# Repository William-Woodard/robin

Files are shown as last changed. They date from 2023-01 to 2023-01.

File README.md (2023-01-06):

# Robin PCB
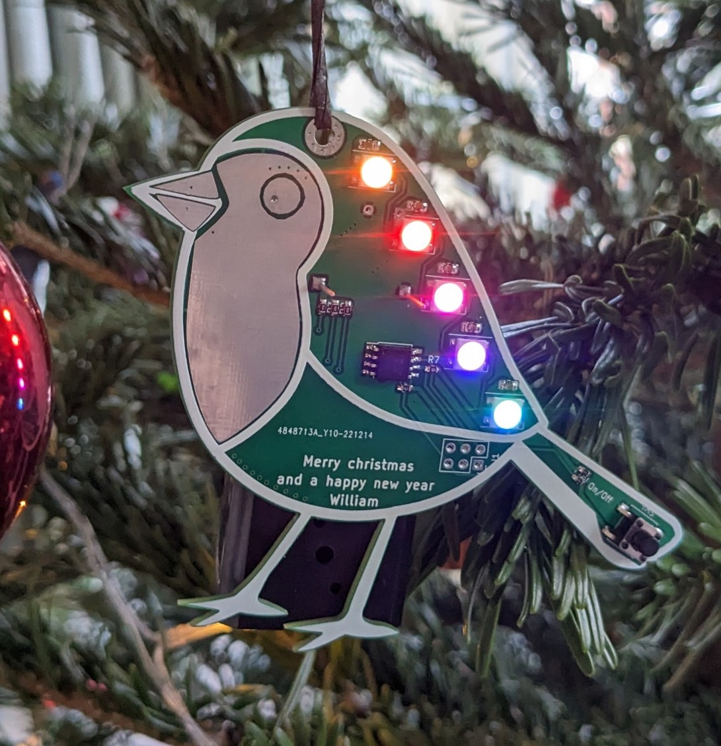
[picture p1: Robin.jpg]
Picture of the PCB

Over Christmas 2022 I made 20 Christmas themed Robin PCBs. Powered by an Attiny85, each PCB has 5 neopixels so show pretty patterns and a buzzer so it can play Christmas music. They have 2 AA batteries and an off switch meaning they should last longer than last years!

## Robin Instructions

Turn the Robin on or off with the button located on the tail. Every time you turn it on it rotates between 2 different patterns. To make it play music, press firmly on one of the spots marked below. You may have to have slightly sweaty hands for it to work :)

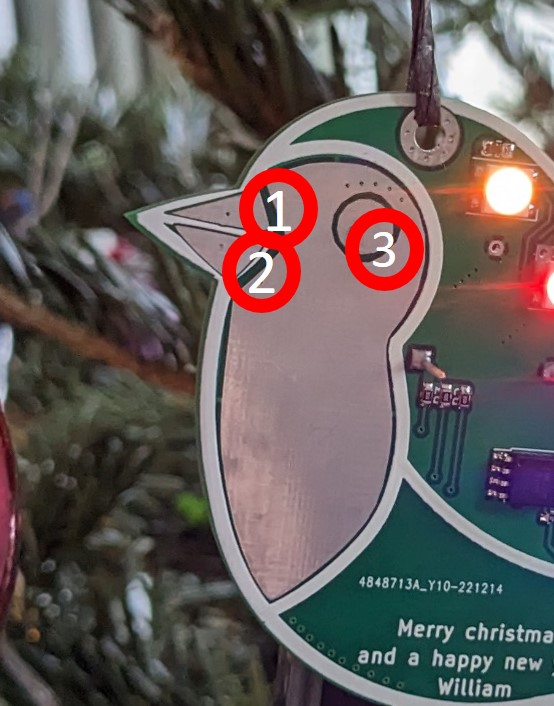
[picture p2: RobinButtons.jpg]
Buttons to press for music


Instead of having 3 buttons for the Christmas songs, I connected 3 of the gpios from the microcontroller to 3 exposed copper pads on the pcb (the eye and the 2 beaks). These are pulled high by a 200k resistor but if you press between the copper pad and ground as shown in the diagram below, you pull the voltage down as current flows through the moisture on your finger. The microcontroller detects that the voltage is reduced so plays a song.

## The assembly process

* I first used a stencil to apply solder paste to the robin
* I then used tweesers to place all the parts onto the board
* I used a hot plate to reflow solder all the components
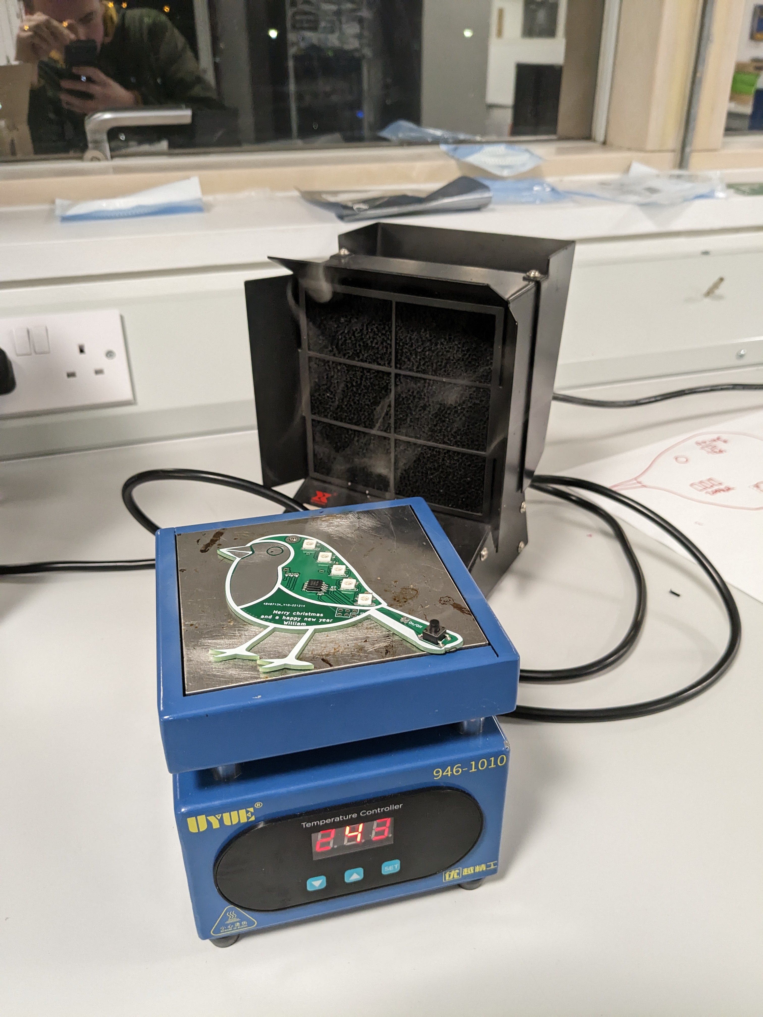
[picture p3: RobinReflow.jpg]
A robin on a hotplate

* I used a soldering iron to attach both the battery holder (through hole) and the buzzer (on the opposite side to the rest of the components)
* I used an arduino to program the microcontroller via spi

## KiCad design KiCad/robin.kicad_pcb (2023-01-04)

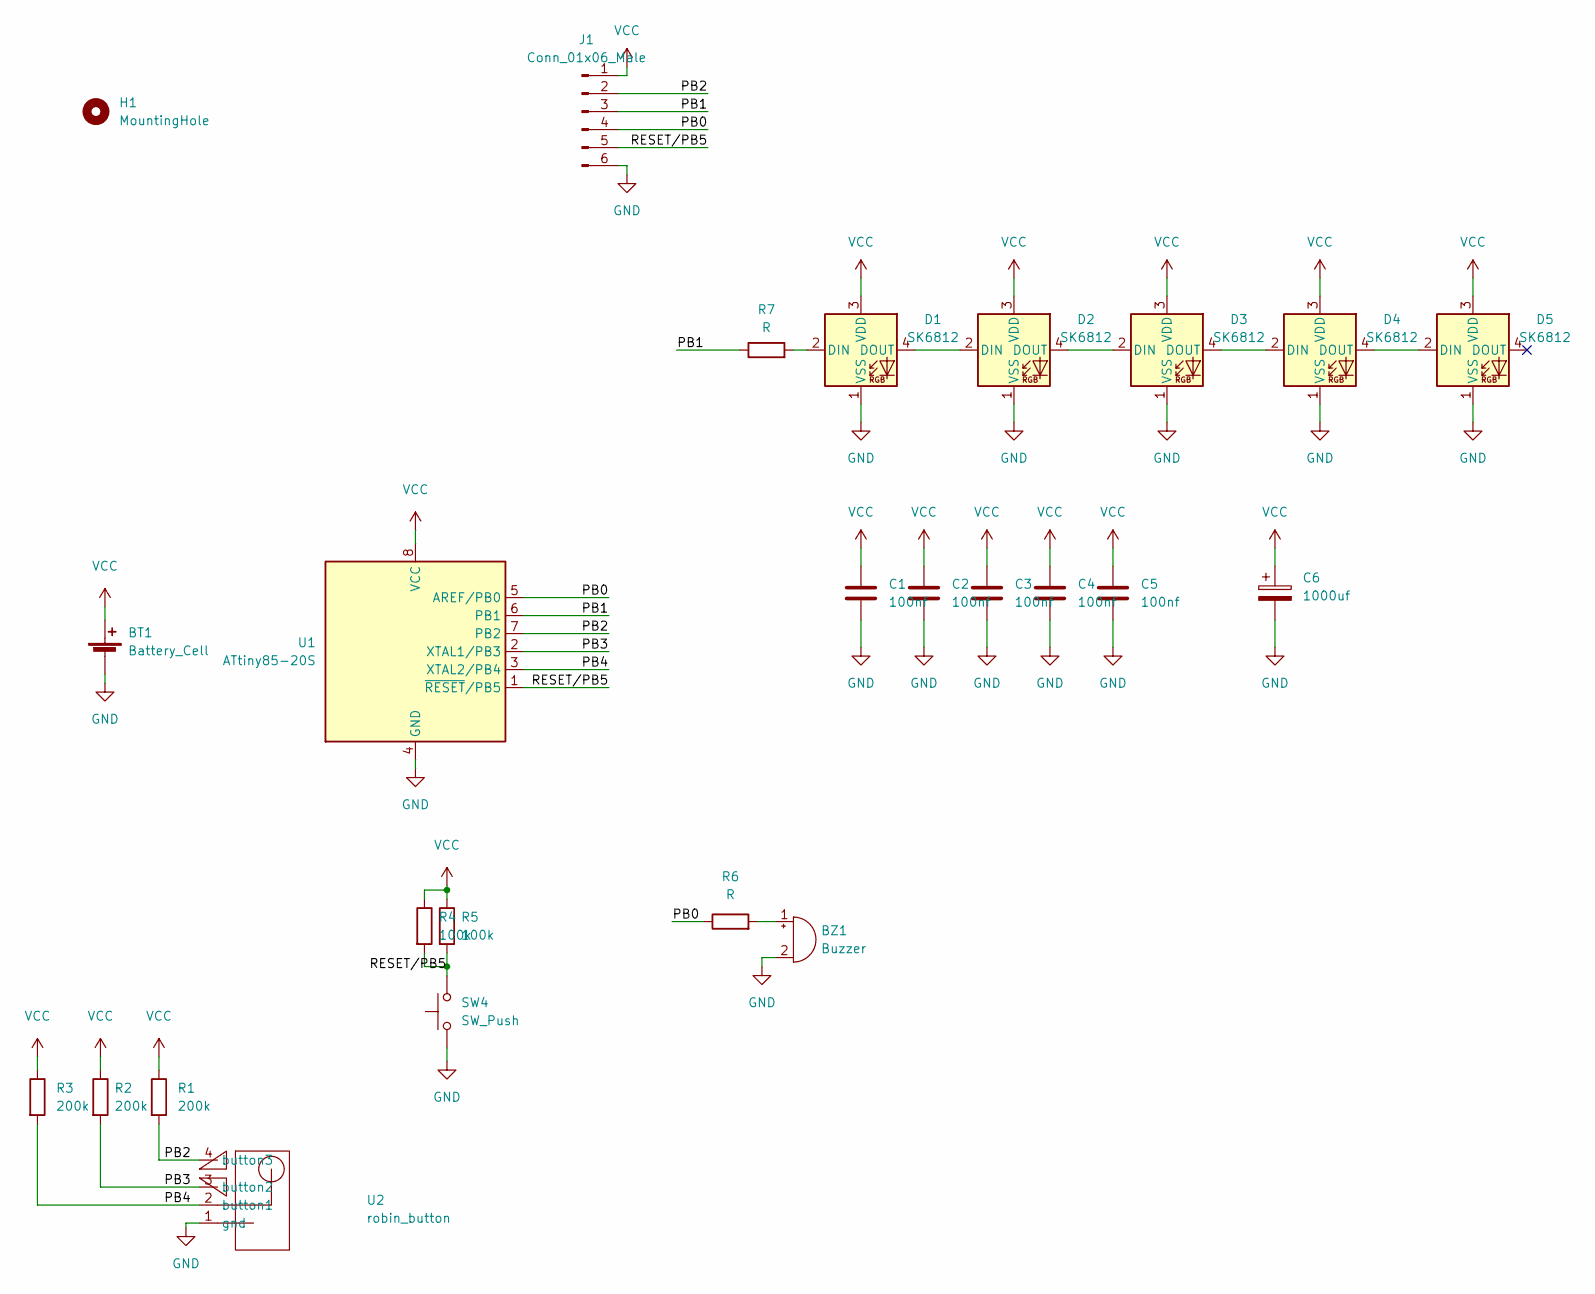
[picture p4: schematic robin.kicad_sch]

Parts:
BT1: Battery_Cell; BatteryHolder_Keystone_2462_2xAA
BZ1: Buzzer; Buzzer_CUI_CPT-9019S-SMT
C1, C2, C3, C4, C5: 100nf; C_0805_2012Metric_Pad1.18x1.45mm_HandSolder
C6: 1000uf; CP_Radial_D8.0mm_P5.00mm
D1, D2, D3, D4, D5: SK6812; LED_SK6812_PLCC4_5.0x5.0mm_P3.2mm
H1: MountingHole; MountingHole_3mm_Pad_Via
J1: Conn_01x06_Male; PinSocket_2x03_P2.54mm_Vertical
R1, R2, R3: 200k; R_0603_1608Metric
R4, R5: 100k; R_0603_1608Metric
R6, R7: R; R_0603_1608Metric
SW4: SW_Push; SW_SPST_B3S-1000
U1: ATtiny85-20S; SOIC-8W_5.3x5.3mm_P1.27mm
U2: robin_button; copp27

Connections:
/PB0: J1.4, R6.1, U1.5 (AREF/PB0)
/PB1: J1.3, R7.1, U1.6 (PB1)
/PB2: J1.2, R1.2, U1.7 (PB2), U2.4 (button3); also elsewhere on the board
/PB3: R2.2, U1.2 (XTAL1/PB3), U2.3 (button2); also elsewhere on the board
/PB4: R3.2, U1.3 (XTAL2/PB4), U2.2 (button1); also elsewhere on the board
/RESET/PB5: J1.5, R4.2, R5.2, SW4.2, U1.1 (~RESET/PB5)
GND: BT1.2 (-), BZ1.2 (+), C1.2, C2.2, C3.2, C4.2, C5.2, C6.2, D1.1 (VSS), D2.1 (VSS), D3.1 (VSS), D4.1 (VSS), D5.1 (VSS), J1.6, SW4.1, U1.4 (GND), U2.1 (gnd); also elsewhere on the board
unnamed: BZ1.1 (-), R6.2
unnamed: D1.2 (DIN), R7.2
unnamed: D1.4 (DOUT), D2.2 (DIN)
unnamed: D2.4 (DOUT), D3.2 (DIN)
unnamed: D3.4 (DOUT), D4.2 (DIN)
unnamed: D4.4 (DOUT), D5.2 (DIN)
VCC: BT1.1 (+), C1.1, C2.1, C3.1, C4.1, C5.1, C6.1, D1.3 (VDD), D2.3 (VDD), D3.3 (VDD), D4.3 (VDD), D5.3 (VDD), J1.1, R1.1, R2.1, R3.1, R4.1, R5.1, U1.8 (VCC)

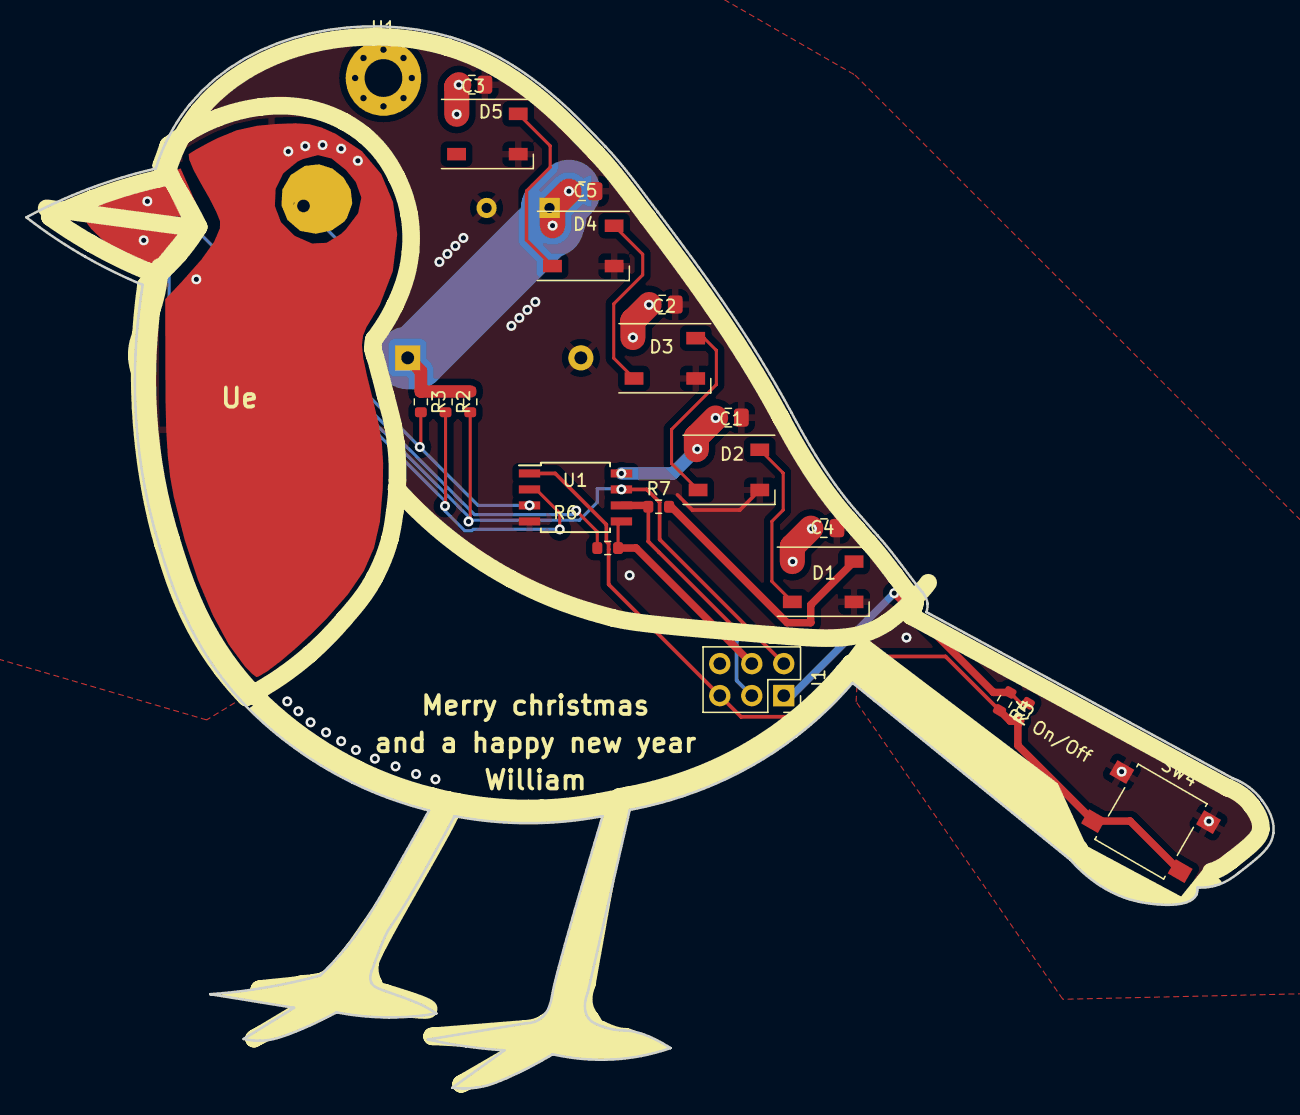
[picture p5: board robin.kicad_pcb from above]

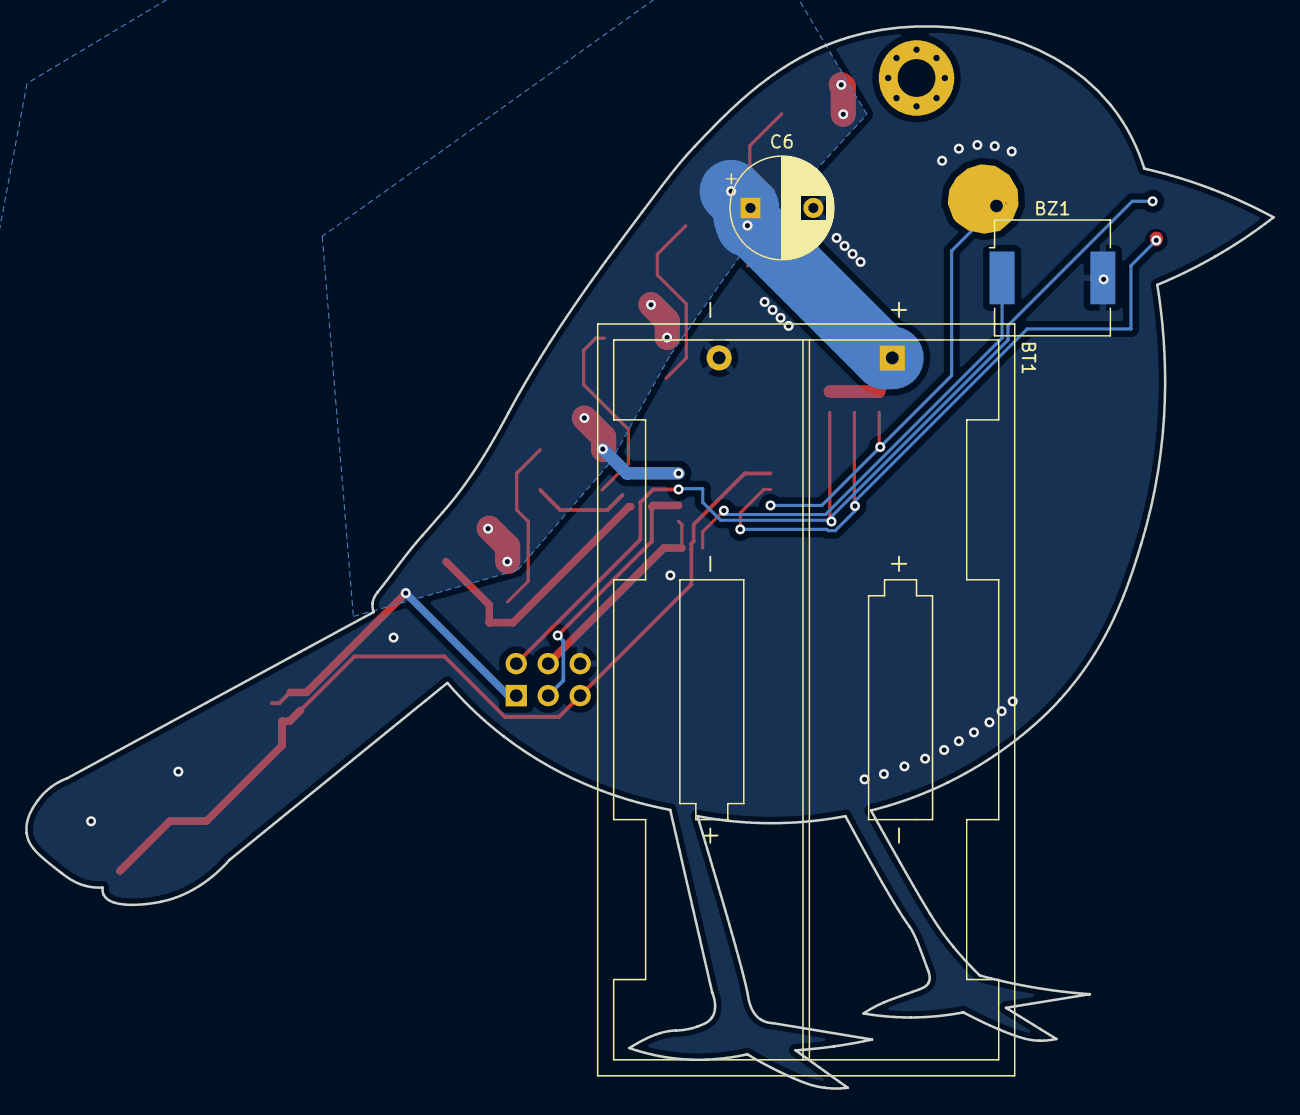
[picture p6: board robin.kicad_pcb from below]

Board: 2 copper layers, 99.1 x 84.4 mm, 25 parts (3 on the bottom side), 14 nets.

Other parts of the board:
Ue: robin_button; copp27

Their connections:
/PB2: Ue.4 (button3); also elsewhere on the board
/PB3: Ue.3 (button2); also elsewhere on the board
/PB4: Ue.2 (button1); also elsewhere on the board
GND: Ue.1 (gnd); also elsewhere on the board

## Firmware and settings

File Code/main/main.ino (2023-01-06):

//Libraries
#include <FastLED.h>
#include "pitches.h"
#include <avr/sleep.h>
#include <EEPROM.h>





//----------------------------------------Constants-----------------------------------
#define BUTTON_THRESHOLD     500   
#define GHUE_ADDITION_MUSIC 100

#define DATA_PIN    1
#define LED_TYPE    WS2811
#define COLOR_ORDER GRB
#define NUM_LEDS    5
CRGB leds[NUM_LEDS];

#define BRIGHTNESS          30
#define FRAMES_PER_SECOND  120

// Jingle Bells

int jingle_melody[] = {
  NOTE_E5, NOTE_E5, NOTE_E5,
  NOTE_E5, NOTE_E5, NOTE_E5,
  NOTE_E5, NOTE_G5, NOTE_C5, NOTE_D5,
  NOTE_E5,
  NOTE_F5, NOTE_F5, NOTE_F5, NOTE_F5,
  NOTE_F5, NOTE_E5, NOTE_E5, NOTE_E5, NOTE_E5,
  NOTE_E5, NOTE_D5, NOTE_D5, NOTE_E5,
  NOTE_D5, NOTE_G5
};

byte jingle_tempo[] = {
  8, 8, 4,
  8, 8, 4,
  8, 8, 8, 8,
  2,
  8, 8, 8, 8,
  8, 8, 8, 16, 16,
  8, 8, 8, 8,
  4, 4
};
   

// We wish you a merry Christmas
int wish_melody[] = {
  NOTE_B3, 
  NOTE_F4, NOTE_F4, NOTE_G4, NOTE_F4, NOTE_E4,
  NOTE_D4, NOTE_D4, NOTE_D4,
  NOTE_G4, NOTE_G4, NOTE_A4, NOTE_G4, NOTE_F4,
  NOTE_E4, NOTE_E4, NOTE_E4,
  NOTE_A4, NOTE_A4, NOTE_B4, NOTE_A4, NOTE_G4,
  NOTE_F4, NOTE_D4, NOTE_B3, NOTE_B3,
  NOTE_D4, NOTE_G4, NOTE_E4,
  NOTE_F4
};

byte wish_tempo[] = {
  4,
  4, 8, 8, 8, 8,
  4, 4, 4,
  4, 8, 8, 8, 8,
  4, 4, 4,
  4, 8, 8, 8, 8,
  4, 4, 8, 8,
  4, 4, 4,
  2
};

// Santa Claus is coming to town

int santa_melody[] = {
  NOTE_G4,
  NOTE_E4, NOTE_F4, NOTE_G4, NOTE_G4, NOTE_G4,
  NOTE_A4, NOTE_B4, NOTE_C5, NOTE_C5, NOTE_C5,
  NOTE_E4, NOTE_F4, NOTE_G4, NOTE_G4, NOTE_G4,
  NOTE_A4, NOTE_G4, NOTE_F4, NOTE_F4,
  NOTE_E4, NOTE_G4, NOTE_C4, NOTE_E4,
  NOTE_D4, NOTE_F4, NOTE_B3,
  NOTE_C4
};

byte santa_tempo[] = {
  8,
  8, 8, 4, 4, 4,
  8, 8, 4, 4, 4,
  8, 8, 4, 4, 4,
  8, 8, 4, 2,
  4, 4, 4, 4,
  4, 2, 4,
  1
};

//--------------------------------------------Global variables-----------------------------
byte digitalSwitch;
byte patterSwitch;

FASTLED_USING_NAMESPACE

CRGBPalette16 currentPalette;
TBlendType    currentBlending;

bool song;
long int old_millis;

bool g_robin_is_on = true;


uint8_t gHue = 0; // rotating "base color" used by many of the patterns



void setup() {
  FastLED.addLeds<LED_TYPE,DATA_PIN,COLOR_ORDER>(leds, NUM_LEDS).setCorrection(TypicalLEDStrip);
  // set master brightness control
  FastLED.setBrightness(BRIGHTNESS);

  //The on/off switch is actually the reset button. To get around this mistake there is a bit in EEPROM that is toggled
  //so it knows that if it used to be on then it should be off and vice verse
  //The other bit in EEPROM stores the previous pattern
  digitalSwitch=EEPROM.read(0);  
  patterSwitch=EEPROM.read(1);


  if (digitalSwitch==0){
    digitalSwitch=!digitalSwitch;   
    EEPROM.write(0, digitalSwitch);  
    FastLED.clear();
    FastLED.show();
    set_sleep_mode(SLEEP_MODE_PWR_DOWN);  
    sleep_enable();     
    sleep_mode(); 
    }

  else{
    digitalSwitch=!digitalSwitch;   
    EEPROM.write(0, digitalSwitch);   
    }   
  if (patterSwitch==0){
    
    patterSwitch=!patterSwitch;   
    EEPROM.write(1, patterSwitch);  
    song = 0;
    }

  else{
    patterSwitch=!patterSwitch;   
    EEPROM.write(1, patterSwitch);   
    song = 1;
    }   

   pinMode(0, OUTPUT); 
  pinMode(5,INPUT);
  
` old_millis = millis();



  currentPalette = RainbowColors_p;
  currentBlending = LINEARBLEND;

}


  
void loop()
{
  if (g_robin_is_on){
    if ((millis()-old_millis)>100){//Every 100ms checks:
    //First checks if any of the song buttons are pressed
    if (analogRead(A1)<BUTTON_THRESHOLD){
    
      int size = sizeof(jingle_melody) / sizeof(int);
        for (int thisNote = 0; thisNote < size; thisNote++) {

          // to calculate the note duration, take one second
          // divided by the note type.
          //e.g. quarter note = 1000 / 4, eighth note = 1000/8, etc.
          int noteDuration = 1000 / jingle_tempo[thisNote];
          for (int i = 0; i <= 4; i=i+2) {
            leds[i].setRGB(255,0,0);
          }
          FastLED.show();
          buzz(0, jingle_melody[thisNote], noteDuration);
        
          // to distinguish the notes, set a minimum time between them.
          // the note's duration + 30% seems to work well:
          int pauseBetweenNotes = noteDuration * 1.30;
          for (int i = 0; i <= 4; i++) {
            leds[i].setRGB(0,255,0);
          }
          FastLED.show();
          delay(pauseBetweenNotes);
        
          // stop the tone playing:
          buzz(0, 0, noteDuration);
          
        }
      }
    if (analogRead(A2)<BUTTON_THRESHOLD){
    
      int size = sizeof(santa_melody) / sizeof(int);
        for (int thisNote = 0; thisNote < size; thisNote++) {

          // to calculate the note duration, take one second
          // divided by the note type.
          //e.g. quarter note = 1000 / 4, eighth note = 1000/8, etc.
          int noteDuration = 1000 / santa_tempo[thisNote];
          for (int i = 0; i <= 4; i=i+1) {
          leds[i].setRGB(0,255,0);
          }
        
          i = santa_melody[thisNote];
          i = i - 250;
          i = i/50;
          i = round(i);
          if (i>4){
            i=4;
          }
          
          leds[i].setRGB(255,0,0);
          
          FastLED.show();
          buzz(0, santa_melody[thisNote], noteDuration);
          
          // to distinguish the notes, set a minimum time between them.
          // the note's duration + 30% seems to work well:
          int pauseBetweenNotes = noteDuration * 1.30;
          for (int i = 0; i <= 4; i=i+1) {
          leds[i].setRGB(0,100,0);
          }
          FastLED.show();
          delay(pauseBetweenNotes);
          
      
          // stop the tone playing:
          buzz(0, 0, noteDuration);
        
          
        }
      }
      if (analogRead(A3)<BUTTON_THRESHOLD){
    
      int size = sizeof(wish_melody) / sizeof(int);
        for (int thisNote = 0; thisNote < size; thisNote++) {

          // to calculate the note duration, take one second
          // divided by the note type.
          //e.g. quarter note = 1000 / 4, eighth note = 1000/8, etc.
          int noteDuration = 1000 / wish_tempo[thisNote];
          rainbow();
          FastLED.show();  
          gHue = gHue+GHUE_ADDITION_MUSIC; 
          buzz(0, wish_melody[thisNote], noteDuration);
          
          // to distinguish the notes, set a minimum time between them.
          // the note's duration + 30% seems to work well:
          int pauseBetweenNotes = noteDuration * 1.30;
          delay(pauseBetweenNotes);
        
      
          // stop the tone playing:
          buzz(0, 0, noteDuration);
          
        }
      }
      old_millis = millis();
    
      
    
    }
    //If no song buttons are pressed then the robin will do the animation
      else{
        if (song){
          rainbow();
          FastLED.show();  
          gHue = gHue+3; 
          FastLED.delay(10); 
        }
        else{
          currentPalette = Holly_p;           
          currentBlending = LINEARBLEND; 
    
          static uint8_t startIndex = 0;
          startIndex = startIndex + 1; /* motion speed */
          
          FillLEDsFromPaletteColors( startIndex);
          
          FastLED.show();
          FastLED.delay(10);
        }
      }
  }


  
}

#define ARRAY_SIZE(A) (sizeof(A) / sizeof((A)[0]))


#define Holly_Green 0x00580c
#define Holly_Red   0xB00402
const TProgmemRGBPalette16 Holly_p FL_PROGMEM =
{  Holly_Green, Holly_Green, Holly_Green, Holly_Green, 
   Holly_Green, Holly_Green, Holly_Green, Holly_Green, 
   Holly_Green, Holly_Green, Holly_Green, Holly_Green, 
   Holly_Green, Holly_Green, Holly_Green, Holly_Red 
};

void rainbow() 
{
  // FastLED's built-in rainbow generator
  fill_rainbow( leds, NUM_LEDS, gHue, 40);
}
void FillLEDsFromPaletteColors( uint8_t colorIndex)
{
    uint8_t brightness = 255;
    
    for( int i = 0; i < NUM_LEDS; ++i) {
        leds[i] = ColorFromPalette( currentPalette, colorIndex, brightness, currentBlending);
        colorIndex += 3;
    }
}


//I couldnt get the tone function to work on the attiny85 so instead I'm using this functino
void buzz(int targetPin, long frequency, long length) {
  
  long delayValue = 1000000 / frequency / 2; // calculate the delay value between transitions
  //// 1 second's worth of microseconds, divided by the frequency, then split in half since
  //// there are two phases to each cycle
  long numCycles = frequency * length / 1000; // calculate the number of cycles for proper timing
  //// multiply frequency, which is really cycles per second, by the number of seconds to
  //// get the total number of cycles to produce
  for (long i = 0; i < numCycles; i++) { // for the calculated length of time...
    digitalWrite(targetPin, HIGH); // write the buzzer pin high to push out the diaphram
    delayMicroseconds(delayValue); // wait for the calculated delay value
    digitalWrite(targetPin, LOW); // write the buzzer pin low to pull back the diaphram
    delayMicroseconds(delayValue); // wait again or the calculated delay value
  }
 

}

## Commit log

2023-01-04 Removed images from arduino example
2023-01-04 Added KiCad files
    [robin.kicad_pcb, robin.kicad_sch]
2023-01-06 added picture of robin on the hot plate
